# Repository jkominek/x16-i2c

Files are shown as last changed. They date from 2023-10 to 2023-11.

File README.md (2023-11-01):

Rough draft of an I2C expansion card for the [Commander X16](https://www.commanderx16.com/)

I don't have any real hardware, and haven't fabbed this. So there's little reason to believe it works.

* Features
  * PCA9548A I2C eight port multiplexer, so you can use a lot of I2C devices without loading the bus down. Also lets you use multiple identical devices, which would otherwise have conflicting addresses.
  * Four I2C ports are brought out [SparkFun Qwiic](https://www.sparkfun.com/qwiic)-style, with 3.3V power.
    * Why that connector? Sparkfun has a lot of Qwiic hardware, and Adafruit as a bunch of [STEMMA QT](https://www.adafruit.com/category/1018) hardware, which is compatible. Some other companies have some similar products. This gets you dozens of compatible IO devices in one fell swoop.
  * Three are headers on the board, with 5V power, for use "inside the case"
  * Last port is on a PCA9615 differential I2C transceiver, for very distant I2C devices.
    * It provides 3.3V and 12V.
    * Intended to be compatible with the [Sparkfun QwiicBus Endpoint](https://www.sparkfun.com/products/16988)
  * One mandatory 3.3V regulator for the external I2C ports.
  * You can add one or two other additional regulators, to provide more power to your I2C devices.

I'll revisit and revise this as more docs come out, and whenever I get real hardware.

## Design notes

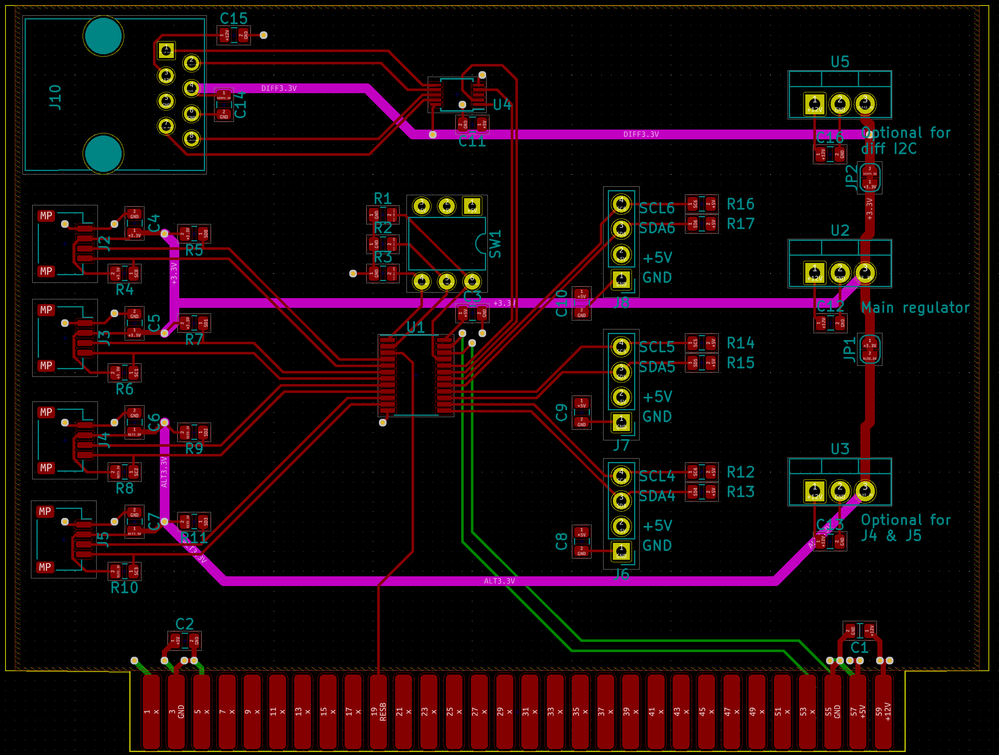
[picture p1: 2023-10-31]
x16-i2c PCB.png

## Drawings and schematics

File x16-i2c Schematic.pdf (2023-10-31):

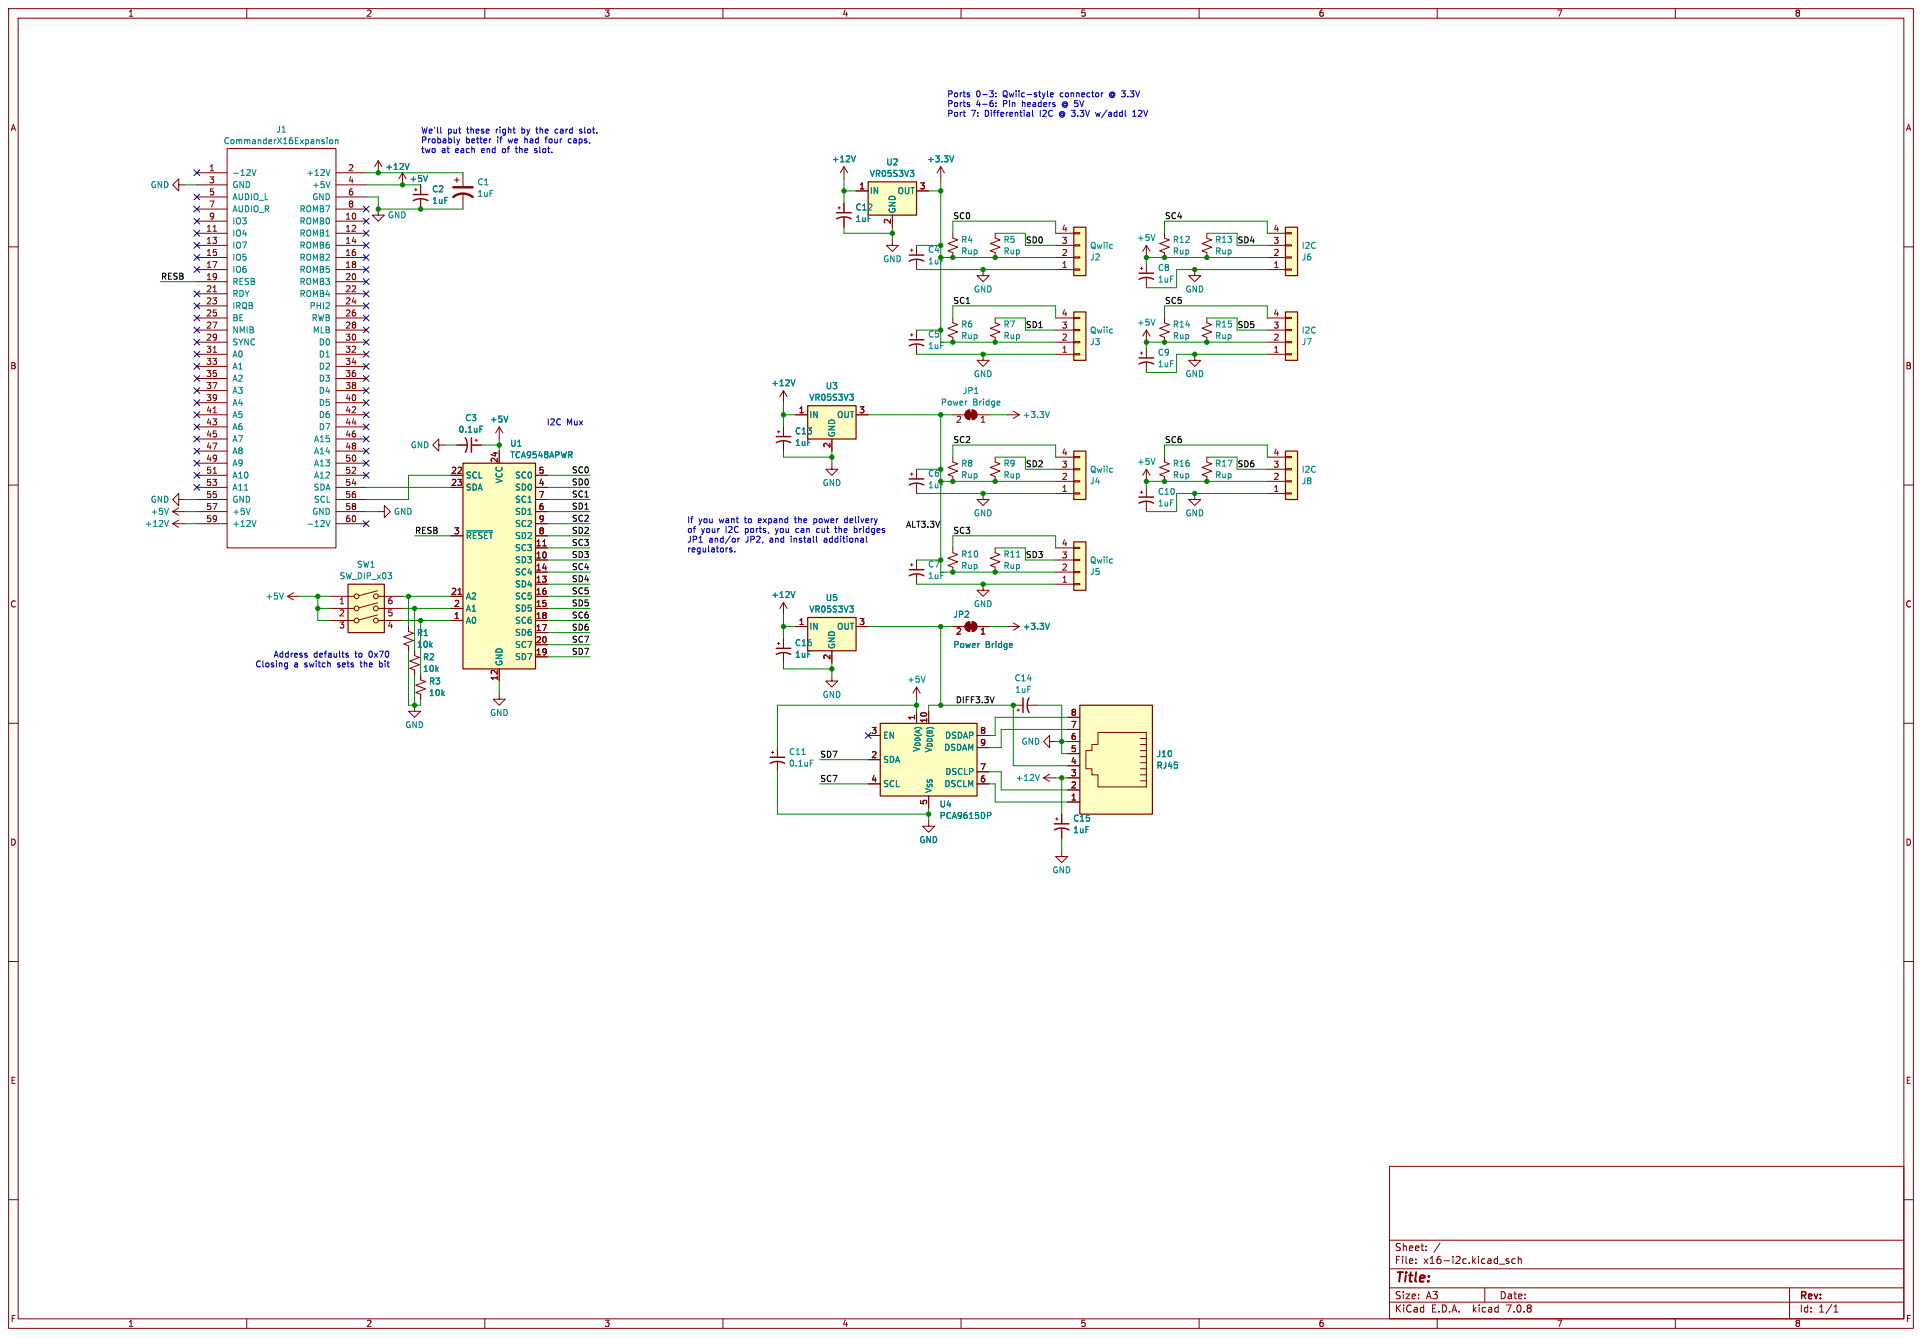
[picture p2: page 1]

two at each end of the slot. R3

J3Qwiic R8 RupGND
JP1 Power Bridge GND GND

If you want to expand the power delivery of your I2C ports, you can cut the bridges

2 OUT 3 U4PCA9615DP V_{DD(A)} 1 V_{DD(B)} 10 SDA 2 EN 3 SCL 4 V_{SS} 5 DSCLM 6 DSCLP 7 DSDAP 8 DSDAM 9 +12V GND

2 OUT 3 U5 VR05S3V3 V_{DD(A)} 1 V_{DD(B)} 10 SDA 2 EN 3 SCL 4 V_{SS} 5 DSCLM 6 DSCLP 7 DSDAP 8 DSDAM 9 U4PCA9615DP

Id: 1/1 Title: File: x16-i2c.kicad_sch Sheet: /

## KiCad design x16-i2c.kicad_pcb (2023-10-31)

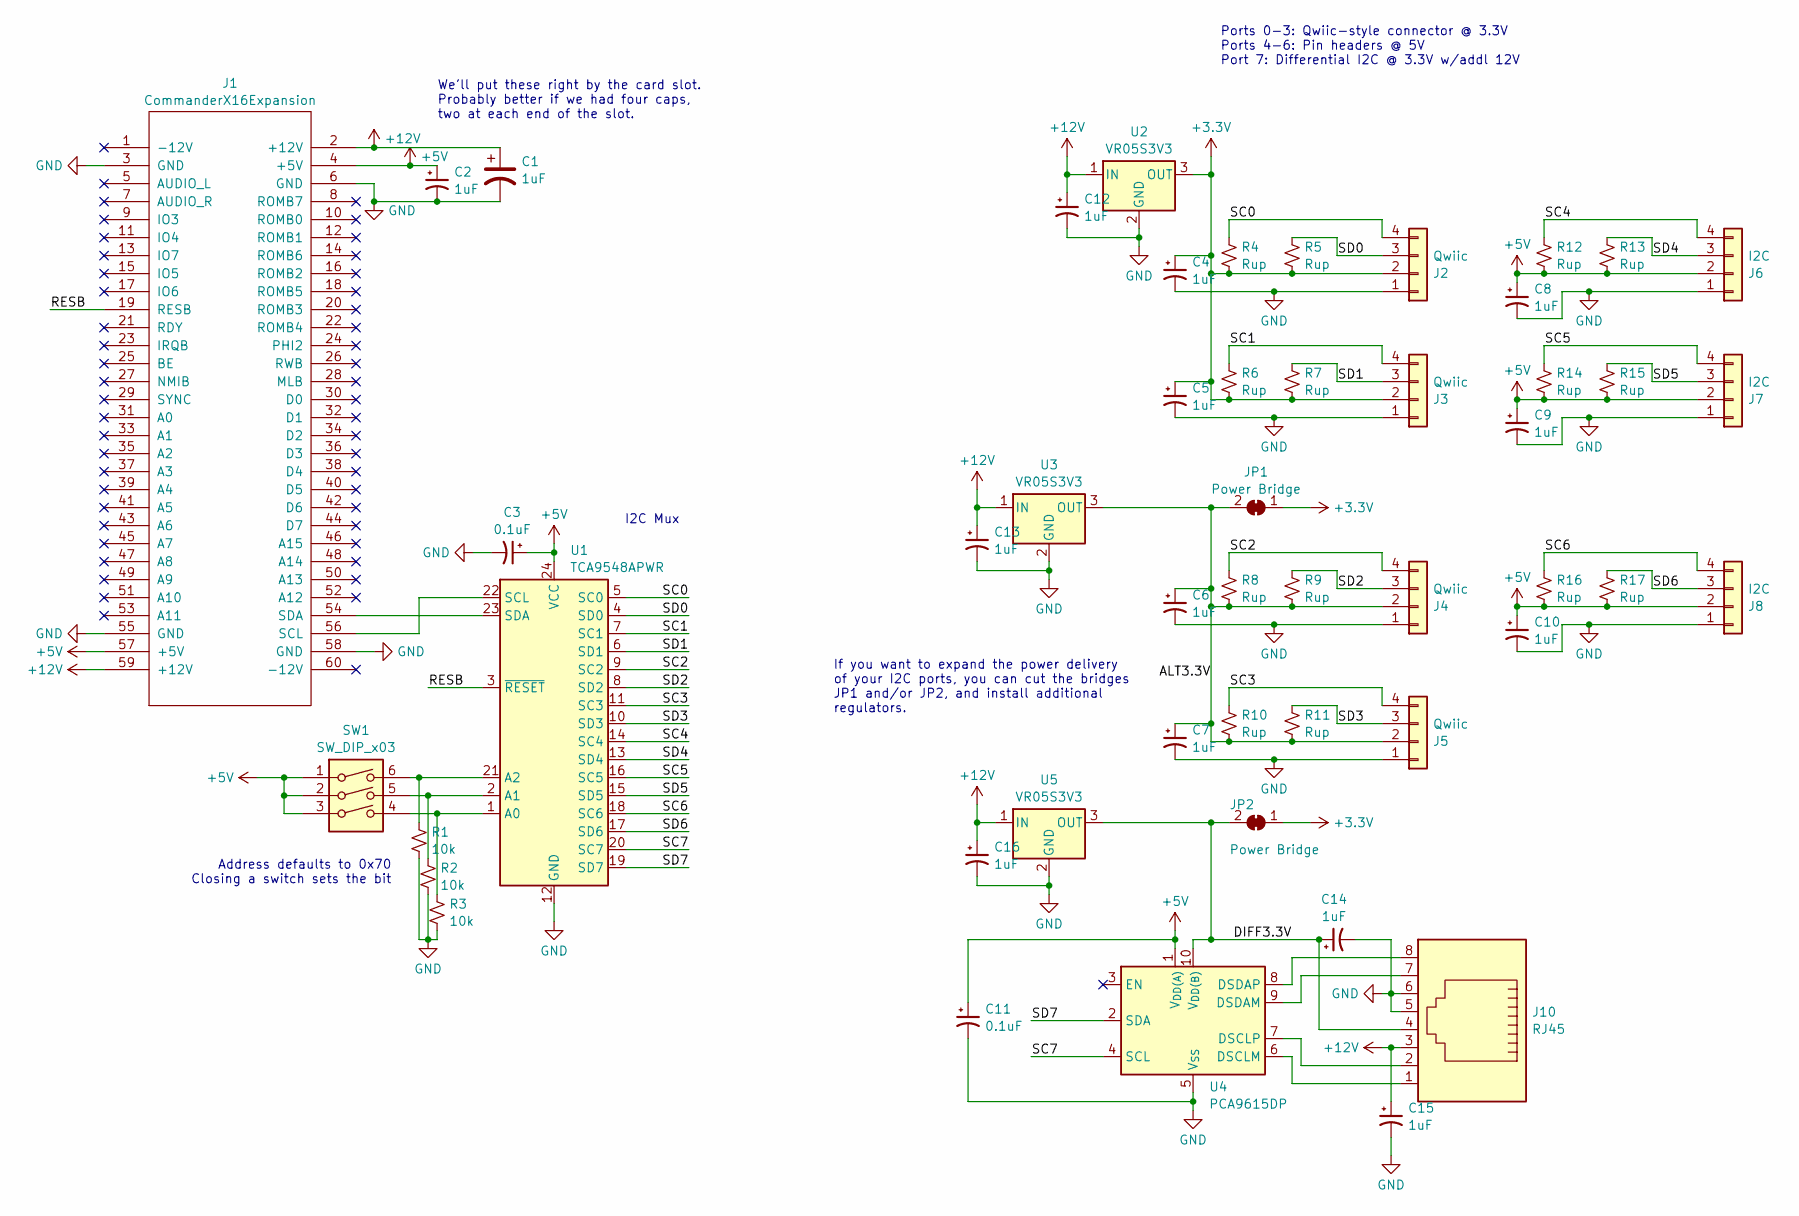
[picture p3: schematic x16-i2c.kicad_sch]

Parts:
C1, C2, C4, C5, C6, C7, C8, C9, C10, C12, C13, C14, C15, C16: 1uF; C_0805_2012Metric
C3, C11: 0.1uF; C_0805_2012Metric
J1: CommanderX16Expansion
J2, J3, J4, J5: Qwiic; JST_SH_SM04B-SRSS-TB_1x04-1MP_P1.00mm_Horizontal
J6, J7, J8: I2C; PinHeader_1x04_P2.54mm_Vertical
J10: RJ45; RJ45_8
JP1, JP2: Power Bridge; SolderJumper-2_P1.3mm_Bridged_RoundedPad1.0x1.5mm
R1, R2, R3: 10k; R_0805_2012Metric
R4, R5, R6, R7, R8, R9, R10, R11, R12, R13, R14, R15, R16, R17: Rup; R_0805_2012Metric
SW1: SW_DIP_x03; DIP-6_W7.62mm
U1: TCA9548APWR; TSSOP-24_4.4x7.8mm_P0.65mm
U2, U3, U5: VR05S3V3; TO-220-3_Vertical
U4: PCA9615DP; TSSOP-10_3x3mm_P0.5mm

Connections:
+3.3V: C4.1, C5.1, J2.2, J3.2, JP1.1 (A), JP2.1 (A), R4.2, R5.2, R6.2, R7.2, U2.3 (OUT)
+5V: C2.1, C3.1, C8.1, C9.1, C10.1, C11.1, J1.4 (+5V), J1.57 (+5V), J6.2, J7.2, J8.2, R12.2, R13.2, R14.2, R15.2, R16.2, R17.2, SW1.1, SW1.2, SW1.3, U1.24 (VCC), U4.1 (V_{DD(A)})
+12V: C1.1, C12.1, C13.1, C15.1, C16.1, J1.2 (+12V), J1.59 (+12V), J10.3, U2.1 (IN), U3.1 (IN), U5.1 (IN)
/ALT3.3V: C6.1, C7.1, J4.2, J5.2, JP1.2 (B), R8.2, R9.2, R10.2, R11.2, U3.3 (OUT)
/DIFF3.3V: C14.1, J10.4, JP2.2 (B), U4.10 (V_{DD(B)}), U5.3 (OUT)
/RESB: J1.19 (RESB), U1.3 (~RESET)
/SC0: J2.4, R4.1, U1.5 (SC0)
/SC1: J3.4, R6.1, U1.7 (SC1)
/SC2: J4.4, R8.1, U1.9 (SC2)
/SC3: J5.4, R10.1, U1.11 (SC3)
/SC4: J6.4, R12.1, U1.14 (SC4)
/SC5: J7.4, R14.1, U1.16 (SC5)
/SC6: J8.4, R16.1, U1.18 (SC6)
/SC7: U1.20 (SC7), U4.4 (SCL)
/SD0: J2.3, R5.1, U1.4 (SD0)
/SD1: J3.3, R7.1, U1.6 (SD1)
/SD2: J4.3, R9.1, U1.8 (SD2)
/SD3: J5.3, R11.1, U1.10 (SD3)
/SD4: J6.3, R13.1, U1.13 (SD4)
/SD5: J7.3, R15.1, U1.15 (SD5)
/SD6: J8.3, R17.1, U1.17 (SD6)
/SD7: U1.19 (SD7), U4.2 (SDA)
GND: C1.2, C2.2, C3.2, C4.2, C5.2, C6.2, C7.2, C8.2, C9.2, C10.2, C11.2, C12.2, C13.2, C14.2, C15.2, C16.2, J1.3 (GND), J1.6 (GND), J1.55 (GND), J1.58 (GND), J2.1, J3.1, J4.1, J5.1, J6.1, J7.1, J8.1, J10.5, J10.6, R1.1, R2.1, R3.1, U1.12 (GND), U2.2 (GND), U3.2 (GND), U4.5 (V_{SS}), U5.2 (GND)
unnamed: J1.56 (SCL), U1.22 (SCL)
unnamed: J1.54 (SDA), U1.23 (SDA)
unnamed: R3.2, SW1.4, U1.1 (A0)
unnamed: R2.2, SW1.5, U1.2 (A1)
unnamed: R1.2, SW1.6, U1.21 (A2)
unnamed: J10.1, U4.6 (DSCLM)
unnamed: J10.2, U4.7 (DSCLP)
unnamed: J10.7, U4.9 (DSDAM)
unnamed: J10.8, U4.8 (DSDAP)

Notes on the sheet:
We'll put these right by the card slot. Probably better if we had four caps, two at each end of the slot.
Ports 0-3: Qwiic-style connector @ 3.3V Ports 4-6: Pin headers @ 5V Port 7: Differential I2C @ 3.3V w/addl 12V
If you want to expand the power delivery of your I2C ports, you can cut the bridges JP1 and/or JP2, and install additional regulators.
I2C Mux
Address defaults to 0x70 Closing a switch sets the bit

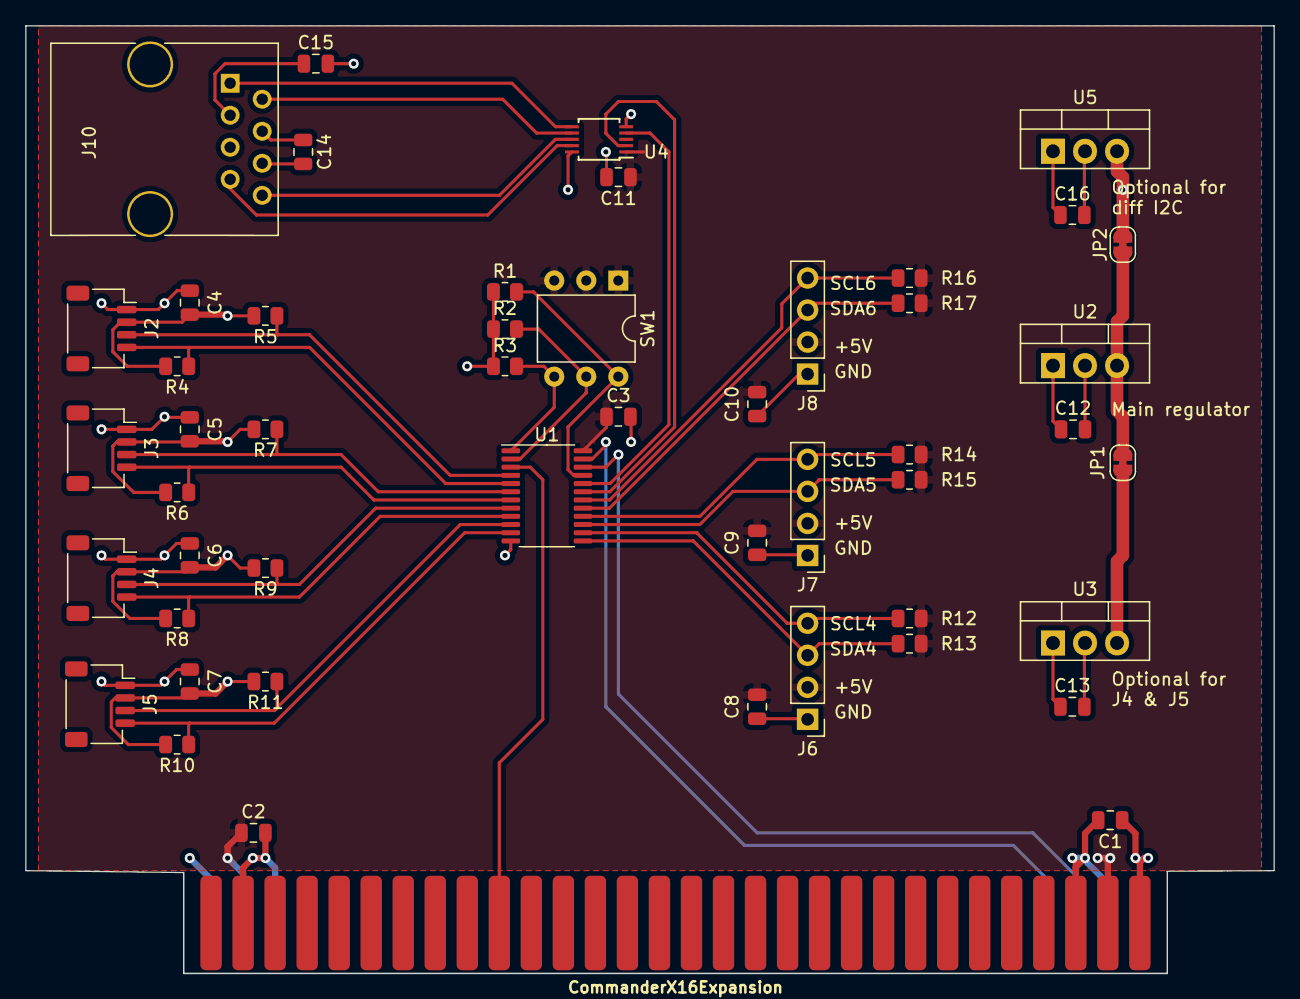
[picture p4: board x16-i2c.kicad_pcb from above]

Board: 4 copper layers, 99.0 x 75.2 mm, 50 parts (0 on the bottom side), 32 nets.
